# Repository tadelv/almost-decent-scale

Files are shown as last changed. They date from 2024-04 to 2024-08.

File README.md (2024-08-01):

# Almost decent scale

Work in progress, a clone of [decent scale](https://decentespresso.com/decentscale_api) for home use

## BOM:
- ESP32 or esp32-s3-mini
- HX711
- Load cell ([either 500g or 750g](https://www.aliexpress.com/item/32670225988.html)) - take care of screw location / orientation, this will affect your enclosure choice.
- some M3 flathead and countersunk screws you probably have lying around
- [M3 threaded inserts](https://www.aliexpress.com/item/1005002897983868.html) if you're going with the 500g design.

## Designs / Enclosures

Currently, two enclosure designs are available in this repo. A build for esp32-s3-mini and a build for esp32, provided by [@randomcoffeesnob](https://github.com/randomcoffeesnob).
The design for esp32-s3-mini is still under active development, while the esp32 and 500g load cell is ready to go!

Pick the one you want, based on the equipment you have. *But be wary, esp32-s3-mini design is really not finished yet!*

## Calibrating over Bluetooth:

The scale supports calibrating over bluetooth. To calibrate the scale, send the `0x03F1` command to `36F5` which will activate the calibration mode.

Once in calibration, the process is the same as when calibrating over Serial port.
- remove all weights and wait for the scale to tare (7 seconds)
- add a known weight
- read the value from the control characteristic `36F5`, I copy the value into calculator on macOS, use byteflip and
change to decimal representation.
- calculate the factor: (units_read_from_char / known_weight)
- write `0x03F2XXXXXXXX` to `36F5` where XX is the uint32(hex) representation of the factor multiplied by 1000 (i.e. `0x03F20000073A` for factor 1.85). Make sure to pad the value with any leading zeroes you need.
- scale should be calibrated now

## TODO:

- conform to DE scale BT protocol (tare, led, version, etc) ✔️ looks ok
- Add own thread logic
- Calibration over BT ✔️
- DE1 tare command handling ✔️
- esp32-s3 target ✔️
- (maybe) web server
- esp32-s2 mini target <- cancelled, only has wifi, maybe one day s3-mini
- esp32-s3-mini ✔️

Use platformio.ini to define pins for your setup. Also if you want to use fake BT for some reason, add `-D BT_COMMS_FAKE`, otherwise use `-D BT_COMMS_NIMBLE`.

Additionally, I had to slow down my esp32s3 devboard - use `-D ESP32S3_SLOWDOWN` to reduce clock speed to 80MHz.

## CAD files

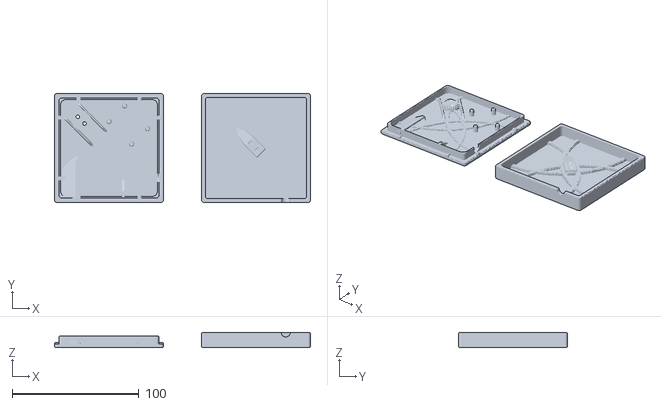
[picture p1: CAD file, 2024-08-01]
designs/esp32-s3-mini/scale-v2.stl
202.0 x 86.0 x 12.0

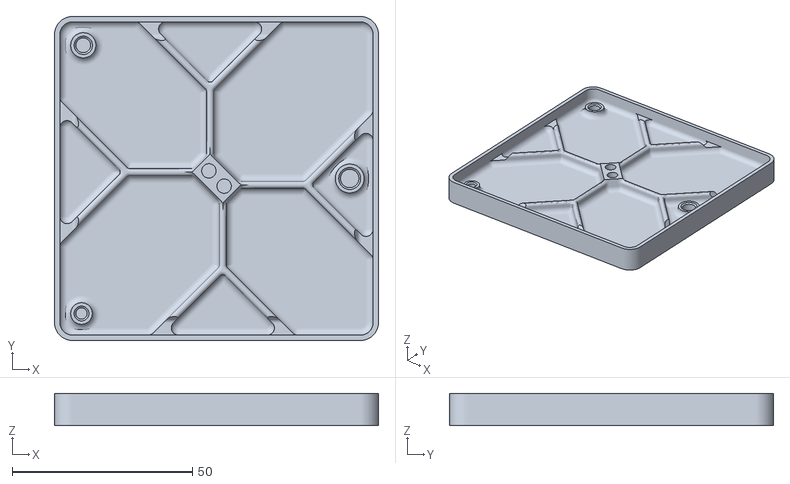
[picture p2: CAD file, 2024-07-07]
designs/esp32/went-scale-upper.stl
90.0 x 90.0 x 9.00

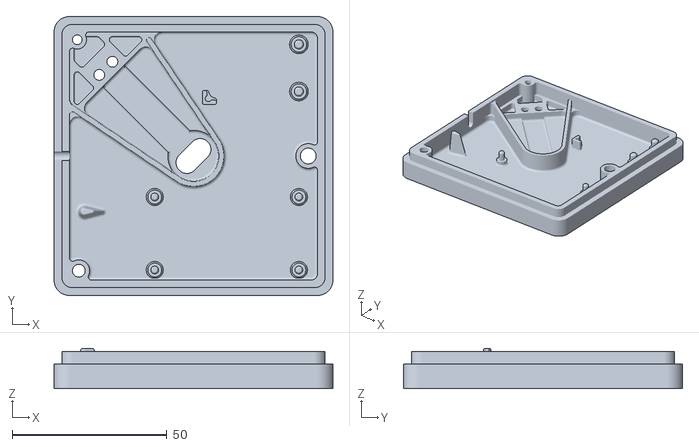
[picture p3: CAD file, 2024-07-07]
designs/esp32/went-scale-lower.stl
90.0 x 90.0 x 13.0

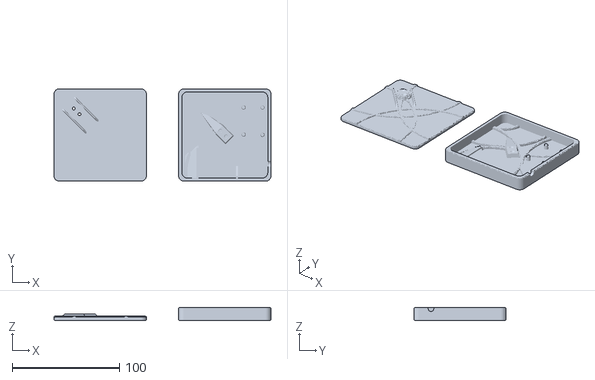
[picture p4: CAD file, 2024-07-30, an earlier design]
designs/esp32-s3-mini/scale.stl
202.0 x 86.0 x 12.0

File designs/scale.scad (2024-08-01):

use <fillets/fillets3d.scad>;
use <fillets/fillets2d.scad>;
use <chamfers/Chamfer.scad>;
use <threads/threads.scad>;

$fn=45;

diameter=4;
boxWidth=86;
wallThickness=3;
loadCellLength=45;

//base();
//loadCell();
//internals();
//top_cover();
bottom_cover();
//%internals();
//#%top_cover_inverted();
translate([boxWidth + 30, 0, 0]) {
        top_cover();
        //round_wall();
}

module round_wall(length = 20, height = 3) {
    topBottomFillet(t = height, b = 0, s = 20, r = height/3)
    rotate_extrude(angle = -90, convexity = 5) {
        difference() {
            square([length, height], center = false);
            square([length - height, height]);
            
        }
    }
}

module support() {
    translate([-5,0,0])
    rotate([0,-90,0])
    translate([3,0,0])
    hull()
    {
        translate([2,2,0]) sphere(r=0.5);
        translate([-2,2,0]) sphere(r=0.5);
        translate([-2,-2,0]) sphere(r=1.5);
        translate([2,26,0]) sphere(r=0.5);
        translate([-2,30,0]) sphere(r=1.5);
    }
}



module top_cover_inverted() {
    translate([boxWidth, boxWidth, 19]) {
        rotate([0,180,90]) {
            top_cover();
        }
    }
}


module top_cover() {
difference() {
union() {
#base();
translate([0,0,3]) {
    #internals();
}
translate([0, boxWidth, 1]) {
        round_wall(length = boxWidth * 0.8, height = 4);
        }
        
        translate([boxWidth, 0, 1]) {
        rotate(180)
                round_wall(length = boxWidth * 0.8, height = 4);
        }
        
        translate([0, 0, 1]) {
        rotate(90)
                round_wall(length = boxWidth * 0.8, height = 4);
        }
        
        translate([boxWidth, boxWidth, 1]) {
        rotate(-90)
                round_wall(length = boxWidth * 0.8, height = 4);
        }
}
connectionCenter=boxWidth/2;
translate([connectionCenter, connectionCenter, 1]) {
    #rotate(a=45) {
    translate([0, 4 - 6, 0]) {
            #screwPoint(15);
        }
            translate([0, 11.5 - 6, 0]) {
            #screwPoint(15);
        }
    }
}
}
}

module bottom_cover() {
    diagonal = sqrt(loadCellLength*loadCellLength)*0.5;
    mountPointXPos=boxWidth/2 - diagonal;
    mountPointYPos=boxWidth/2 + diagonal;
    height = 3;
    difference() {
        union() {
            topBottomFillet(t=height,b=0,r=1,s=30)
            cover(z=height);
            translate([mountPointXPos +0.5, mountPointYPos -0.5, 0]) {
                color("#f0f")
                topFillet(t=6,r=4,s=40)
                linear_extrude(height=6)
                rounding2d(5)
                fillet2d(5)
                square(16, center=true);
                translate([11,-15,0.5])
                rotate(45)
                support();
                translate([22,-4,0.5])
                rotate(45)
                support();
            }


            translate([0, boxWidth, 1]) {
            round_wall(length = boxWidth * 0.8);
            }
            
            translate([boxWidth, 0, 1]) {
            rotate(180)
            round_wall(length = boxWidth * 0.8);
            }
            
            translate([0, 0, 1]) {
            rotate(90)
            round_wall(length = boxWidth * 0.8);
            }
            
            translate([boxWidth, boxWidth, 1]) {
            rotate(-90)
            round_wall(length = boxWidth * 0.8);
            }
            
        #innerWall(height);

            // esp32s3 connection
        espMove = wallThickness + 2;
        translate([espMove + 37.5 + 12, espMove, height])
        rotate(90) {
            #%esp32s3mini();
            translate([-2, 36,-1])
            difference() {
                hull() {
                    cube([1, 2, 5]);
                    translate([30, 0, 0])
                    cube([1, 2, 5]);
                    translate([33,0,0])
                    cube([1, 2, 0.1]); 
                    translate([2,5,0])
                    cube([20,10,0.1]);
                }
                translate([4,1,2])
                hull() {
                    sphere(d=4);
                    translate([26,0,0])
                    sphere(d=4);
                }
            }
            translate([-1, -0.9,-1])
            hull() {
                cube([5, 2, 5]);
                translate([15,0,0])
                cube([1, 2, 0.1]);
            }
            
        }

            // hx711 connection
            rotate(45)
            translate([boxWidth * 0.85, boxWidth * -0.15, 4.9]) {
            %hx711();
                footHeight = 5;
                    translate([2.5,2.5,-2])
                    color("#f00")
                    cylinder(r1=2,r2=1.5, h=footHeight);
                    
                    translate([2.5,27.7,-2])
                    color("#ff0")
                    cylinder(r1=2,r2=1.5, h=footHeight);

                    translate([20,27.7,-2])
                    color("#f0f")
                    cylinder(r1=2,r2=1.5, h=footHeight);
                    
                    translate([20,2.25,-2])
                    color("#0ff")
                    cylinder(r1=2,r2=1.5, h=footHeight);
            }
        }
            holeOffset = -4.5;
            counterHoleDiameter = diameter+1.5;//diameter + 1.5;
            translate([mountPointXPos, mountPointYPos, 0]) {
                rotate(45) {
            translate([0, holeOffset, 0]) {
            cylinder(h=3, r1=(diameter+3)/2, r2=diameter/2);
                            #screwPoint(15);
                        }
                        translate([0, holeOffset + 7.5, 0]) {
                        cylinder(h=3, r1=(diameter+3)/2, r2=diameter/2);
                            #screwPoint(15);
                        }
                        }
            }


        }
}

module innerWall(height) {
    innerWallOffset = wallThickness * 1.2;
    color("red")
    
    translate([innerWallOffset, innerWallOffset, 0])
    difference() {
    #topFillet(t = height * 3, r = 0.5, s = 30)
    linear_extrude(height = height * 3)
//    rounding2d(1.01)
//        fillet2d(0.9)
            fillet2d(5)
            difference() {
              rounding2d(2)
              square(boxWidth - 2 * innerWallOffset);
              translate([1, 1, 0])
              rounding2d(1)
              square(boxWidth - 2 * innerWallOffset - 2);
            }
      translate([boxWidth - innerWallOffset * 2.8, 16, height * 2.5]) {
//            sphere(r=wallThickness * 1.2);
    rotate([0,90,0])
    #cylinder(h = 5, r = wallThickness * 1.2);
        } 
     }

}

module loadCell() { 
    difference() {
        cube([9, 45, 6]);
        translate([4.5, 4, -1]) {
            screwPoint();
        }
        translate([4.5, 11.5, -1]) {
            screwPoint();
        }
        translate([4.5, 45 - 11.5, -1]) {
            screwPoint();
        }
        translate([4.5, 45 - 4, -1]) {
            screwPoint();
        }
    }
}

module screwPoint(height=12) {
    ScrewThread(diameter, height)
    cylinder(height, d=2);
}

module base() {
difference() {
        topBottomFillet(t=12, b=0,r=1,s=30)
        cover(z=12);
        translate([wallThickness, wallThickness, wallThickness]) {
            cover(boxWidth - 2*wallThickness, 10);
        }
        translate([boxWidth - 19.5, -1, 12]) {
//            sphere(r=wallThickness);
rotate([0, 90, 90])
cylinder(5, r = wallThickness * 1.2);
        }
}
}

module cover(x=boxWidth, z=1) {
// topBottomFillet(t=1.5,b=0,r=0.5,s=10)
    linear_extrude(height=z)
    rounding2d(2)
    square([x,x]);
}

module internals() {
    connectionCenter=boxWidth/2;

    translate([connectionCenter, connectionCenter, 1]) {
        #%rotate(a=45) {
            color("#0f0")
            translate([-4.5, -6, 3]) {
                #%loadCell();
            }
        }
        rotate(45)
        translate([0,0,0])
        difference() {
            translate([0,1,-1])
            hull() {
                cube([11,15, 0.1], center = true);
                translate([0,0,3])
                cube([9,13,1], center = true);
                translate([0, 20, 0])
                cube([2, 20, 0.1], center = true);
            }
        }
    }
}

module esp32s3mini() {
    color("#f0f")
    cube([26.5, 37.5, 5]);
} 

module hx711() {
    difference() {
        color("#0f2")
        cube([22.5, 30.2, 3]);
        translate([2.5,2.5,0])
        cylinder(r=1.9, h=4);
        translate([2.5,27.7,0])
        cylinder(r=1.9, h=4);
        translate([20,27.7,0])
        cylinder(r=1.9, h=4);
        translate([20,2.5,0])
        cylinder(r=1.9, h=4);
    }
}

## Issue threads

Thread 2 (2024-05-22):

lolin32_lite

winner69, 2024-05-22:
I'm a beginner and I want to use the WEMOS LOLIN32 Lite board. Can you give me some advice? I've been trying to use the platformio.ini file all day and it keeps giving me the following error:

[env]
platform = espressif32
test_framework = googletest

[env:native]
platform = native
lib_deps =
	HX711
	h2zero/NimBLE-Arduino@^1.4.1

[scale-core]
framework = arduino
; board = esp32-s3-devkitm-1
lib_deps =
	HX711
	h2zero/NimBLE-Arduino@^1.4.1
build_flags =
  -std=c++2a
  ; -D LV_CONF_PATH="${PROJECT_DIR}/include/lv_conf.h"

[env:elolin32_lite]
extends = scale-core
board = lolin32_lite
monitor_speed = 115200
build_flags =
  ${scale-core.build_flags}
  -D LOADCELL_DOUT_PIN=17
  -D LOADCELL_SCK_PIN=18

[env:esp32-s3-mini]
extends = scale-core
board = lolin_s3_mini
monitor_speed = 115200
monitor_filters = send_on_enter
monitor_eol = LF
build_flags =
  ${scale-core.build_flags}
  -DARDUINO_USB_CDC_ON_BOOT
  -DBOARD_HAS_PSRAM
  -DCORE_DEBUG_LEVEL=3
  -D LOADCELL_DOUT_PIN=8
  -D LOADCELL_SCK_PIN=6
  -D BT_COMMS_NIMBLE
  -D DEBUG_SERIAL=Serial
  -D LOGSerial=Serial

show error
Environment    Status    Duration
-------------  --------  ------------
native         FAILED    00:00:00.701
elolin32_lite  FAILED    00:00:05.565
esp32-s3-mini  SUCCESS   00:00:25.366

src/main.cpp:15:3: error: 'LOGSerial' was not declared in this scope
src/main.cpp:25:3: error: 'LOGSerial' was not declared in this scope
src/main.cpp:48:7: error: 'LOGSerial' was not declared in this scope
*** [.pio\build\elolin32_lite\src\main.cpp.o] Error 1

tadelv, 2024-05-23:
Hey, you're missing the defines for DEBUG_SERIAL and LOGSerial! Add this to platformio.ini:

```
[env:elolin32_lite]
extends = scale-core
board = lolin32_lite
monitor_speed = 115200
build_flags =
${scale-core.build_flags}
-D LOADCELL_DOUT_PIN=17
-D LOADCELL_SCK_PIN=18
-D BT_COMMS_NIMBLE
-D DEBUG_SERIAL=Serial
-D LOGSerial=Serial
```

winner69, 2024-05-24:
The code successfully flashes onto the ESP32 and can connect to the app,
but it can't send any data to the application (specifically weight). I've already tested the load cell and it works with other code.

tadelv, 2024-05-24:
Ok, one step closer.

I assume when you say there’s no data, it’s sending gibberish? Or is it
zeros?

If you’re getting zero weight all the time, it might also be a wiring
issue.

I would suggest, that you calibrate the scale again. Either follow the
approach described in readme, via bluetooth, or have the scale connected to
the computer and use the serial monitor in platformio to send ‘c’ to start
calibration, have a known weight ready and then when it tells you the units
number, press ‘f’ to enter and store the factor.

Hope this helps

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

winner69, 2024-05-25:
Thank you, I'll try :)

Closed 2024-05-25.

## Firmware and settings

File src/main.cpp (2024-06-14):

#include <Arduino.h>
#include <EEPROM.h>
#include <almost-decent.h>
#ifdef ESP32S3_SLOWDOWN
#include "soc/rtc.h"
#endif


AlmostDecentScale scale(LOADCELL_DOUT_PIN, LOADCELL_SCK_PIN);

const size_t eepromSize = sizeof(float);
EEPROMClass storage("scaleFactor");

void scaleLog(const char *message) {
  LOGSerial.printf("[scale]: %s\n", message);
}

void saveScaleFactor(float factor) {
  LOGSerial.printf("saving factor %.5f for next time\n", factor);
  storage.writeFloat(0, factor);
  storage.commit();
}

void setup() {
  #ifdef ESP32S3_SLOWDOWN
  setCpuFrequencyMhz(80);
  yield();
  #endif
  
  delay(2 * 1000);
  LOGSerial.begin(115200);
  LOGSerial.println("Starting scale");
  #ifdef ESP32S3_SLOWDOWN
  LOGSerial.printf("cpufreq: %d\n", getCpuFrequencyMhz());
  LOGSerial.printf("apbfreq: %d\n", getApbFrequency());
  LOGSerial.printf("xtalfreq: %d\n", getXtalFrequencyMhz());
  #endif
  scale.m_logCallback = scaleLog;
  scale.m_factorCallback = saveScaleFactor;
  scale.initialize();
  if (scale.getState() == ScaleState::error) {
    LOGSerial.println("failed to init scale ... will not continue");
    while (1);
  }

  storage.begin(eepromSize);
  float factor = storage.readFloat(0);
  LOGSerial.printf("stored factor: %f\n", factor);
  scale.setFactor(factor);
  scale.begin();
  LOGSerial.printf("scale state: %s\n", scale.getStateString());
}

void loop() {
  if (LOGSerial.available()) {
    char cmd[3];
    LOGSerial.readBytes(cmd, 2);
    switch (cmd[0]) {
      case 'c':
        scale.calibration();
        break;
      case 'f':
      {
        LOGSerial.println("enter scale factor");
        while (LOGSerial.available() == 0) {};
        String factorString = LOGSerial.readStringUntil('\n');
        LOGSerial.printf("reading is: %s\n", factorString.c_str());
        float factorFloat = factorString.toFloat();
        LOGSerial.printf("factor is: %f\n", factorFloat);
        if (factorFloat == 0)
        {
          break;
        }
        scale.setFactor(factorFloat);
      }
        break;
      case 't':
        scale.tare();
        break;
    }
  }
  scale.tick();
}

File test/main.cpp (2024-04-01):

#include <gtest/gtest.h>
// uncomment line below if you plan to use GMock
// #include <gmock/gmock.h>

// TEST(...)
// TEST_F(...)

#include <almost-decent.h>

#if defined(ARDUINO)
#include <Arduino.h>

void setup()
{
  // should be the same value as for the `test_speed` option in "platformio.ini"
  // default value is test_speed=115200
  Serial.begin(115200);

  ::testing::InitGoogleTest();
  // if you plan to use GMock, replace the line above with
  // ::testing::InitGoogleMock();
}

void loop()
{
  // Run tests
  if (RUN_ALL_TESTS())
    ;

  // sleep for 1 sec
  delay(1000);
}

#else
int main(int argc, char **argv)
{
  ::testing::InitGoogleTest(&argc, argv);
  // if you plan to use GMock, replace the line above with
  // ::testing::InitGoogleMock(&argc, argv);

  if (RUN_ALL_TESTS())
    ;

  // std::cout << formatWeightWithTimestamp(22, 0, 0, 10) << std::endl;
  // std::cout << formatWeightWithTimestamp(0, 1, 2, 3) << std::endl;
  // std::cout << formatWeightWithTimestamp(101, 1, 2, 4) << std::endl;
  // std::cout << formatWeightWithTimestamp(1940, 1, 2, 5) << std::endl;
  // std::cout << formatWeightWithTimestamp(7059, 1, 2, 6) << std::endl;
  // std::cout << formatWeightWithTimestamp(11180, 1, 2, 7) << std::endl;

  // Always return zero-code and allow PlatformIO to parse results
  return 0;
}
#endif

TEST(decent, formatsMessage) {
  EXPECT_EQ("03CE001600000A0000DB", formatWeightWithTimestamp(22, 0, 0, 10));
  EXPECT_EQ("03CE00000102030000CD", formatWeightWithTimestamp(0, 1, 2, 3));
  EXPECT_EQ("03CE00650102040000A8", formatWeightWithTimestamp(101, 1, 2, 4));
  EXPECT_EQ("03CE079401020500005E", formatWeightWithTimestamp(1940, 1, 2, 5));
  EXPECT_EQ("03CE1B93010206000045", formatWeightWithTimestamp(7059, 1, 2, 6));
  EXPECT_EQ("03CE2BAC01020700004A", formatWeightWithTimestamp(11180, 1, 2, 7));
}

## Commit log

2024-04-07 almost calibrating
2024-04-07 fix switch
2024-04-07 tweak calibration
2024-04-08 store calibration factor in eeprom
2024-04-09 add BT calibration and setFactor
2024-04-22 add milligrams
2024-04-26 add BT calibration instructions
2024-06-09 wip scale parts
    [scale.scad, scale.stl]
2024-06-11 wip scalable design
    [scale.scad]
2024-06-11 almost there, possibly
    [scale.scad]
2024-06-11 hide hx711
    [scale.scad]
2024-06-14 save factor when calibrating via bluetooth
2024-06-14 increase thread diameter and base thickness
    [scale.scad, scale.stl]
2024-06-28 tweak bottom screw holes and add support to bottom plate
    [scale.scad]
2024-07-07 add supports and other improvements
    [scale.scad]
2024-07-07 different top standoff
    [scale.scad]
2024-07-07 tweaks for chips and loadcell
    [scale.scad]
2024-07-07 final tweaks
    [scale.scad, scale.stl]
2024-07-07 update readme and add designs
    [scale.stl, went-scale-lower.stl, went-scale-upper.stl]
2024-07-08 add inserts to readme
2024-07-21 wip scale top
    [scale.scad, scale.stl]
2024-07-21 stress the unfinished-ness of esp32-s3-mini design
2024-07-30 final s3 design before drastic changes
    [scale.scad, scale.stl]
2024-07-30 reverse approach
    [scale-v2.stl, scale.scad]
2024-08-01 add inverted s3 design
    [scale-v2.stl, scale.scad]
2024-08-01 spin off a new task when calibrating, formatting
